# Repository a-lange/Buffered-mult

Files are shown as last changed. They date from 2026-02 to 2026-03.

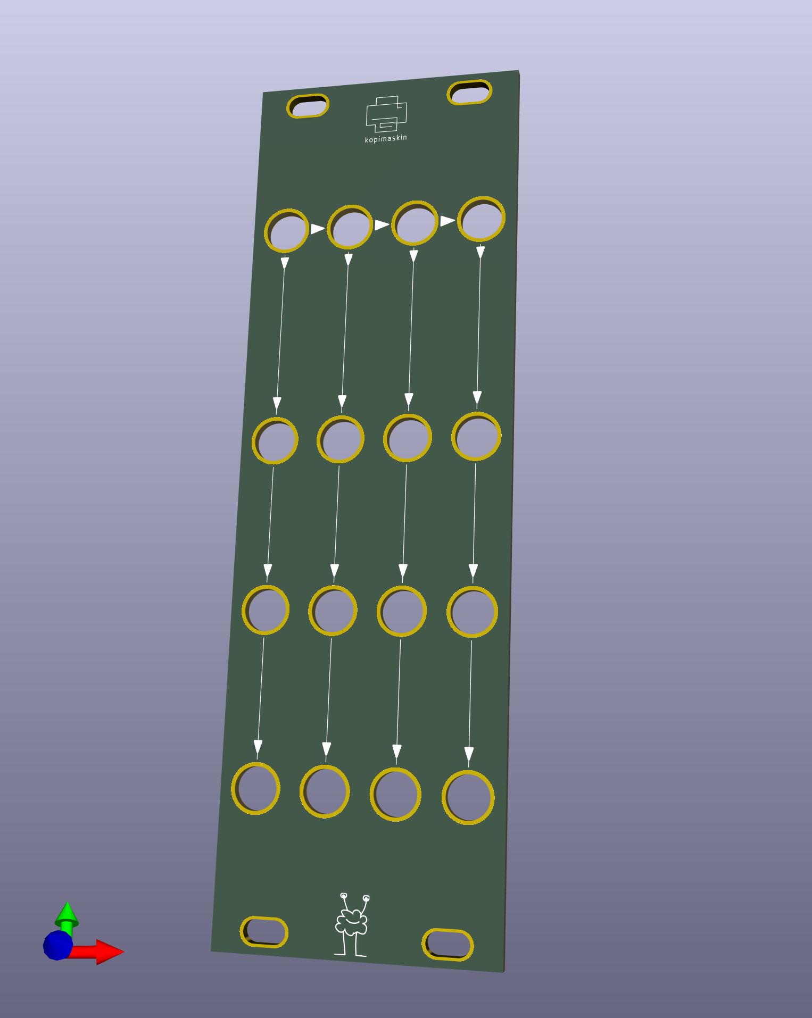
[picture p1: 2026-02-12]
PANEL.png

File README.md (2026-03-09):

This is a buffered mult, made in Kicad for 8HP format. 

It is tested, and works.

For now there is a few minor issues:
- power connector is too close to the edge, so it overhangs a tiny bit. So use an unkeyed pin-header and note that -12v(red stripe) is towards the edge of the board.
- GND is missing on the top jacks, easily patched manually.

The front panel is reversible, the back has a simpler layout with no logo, text or copier.

Use it however you like.

The text says 'copier' in Norwegian, and the creature on the bottom is the friendly "ullmann"(wool-man).
PANEL

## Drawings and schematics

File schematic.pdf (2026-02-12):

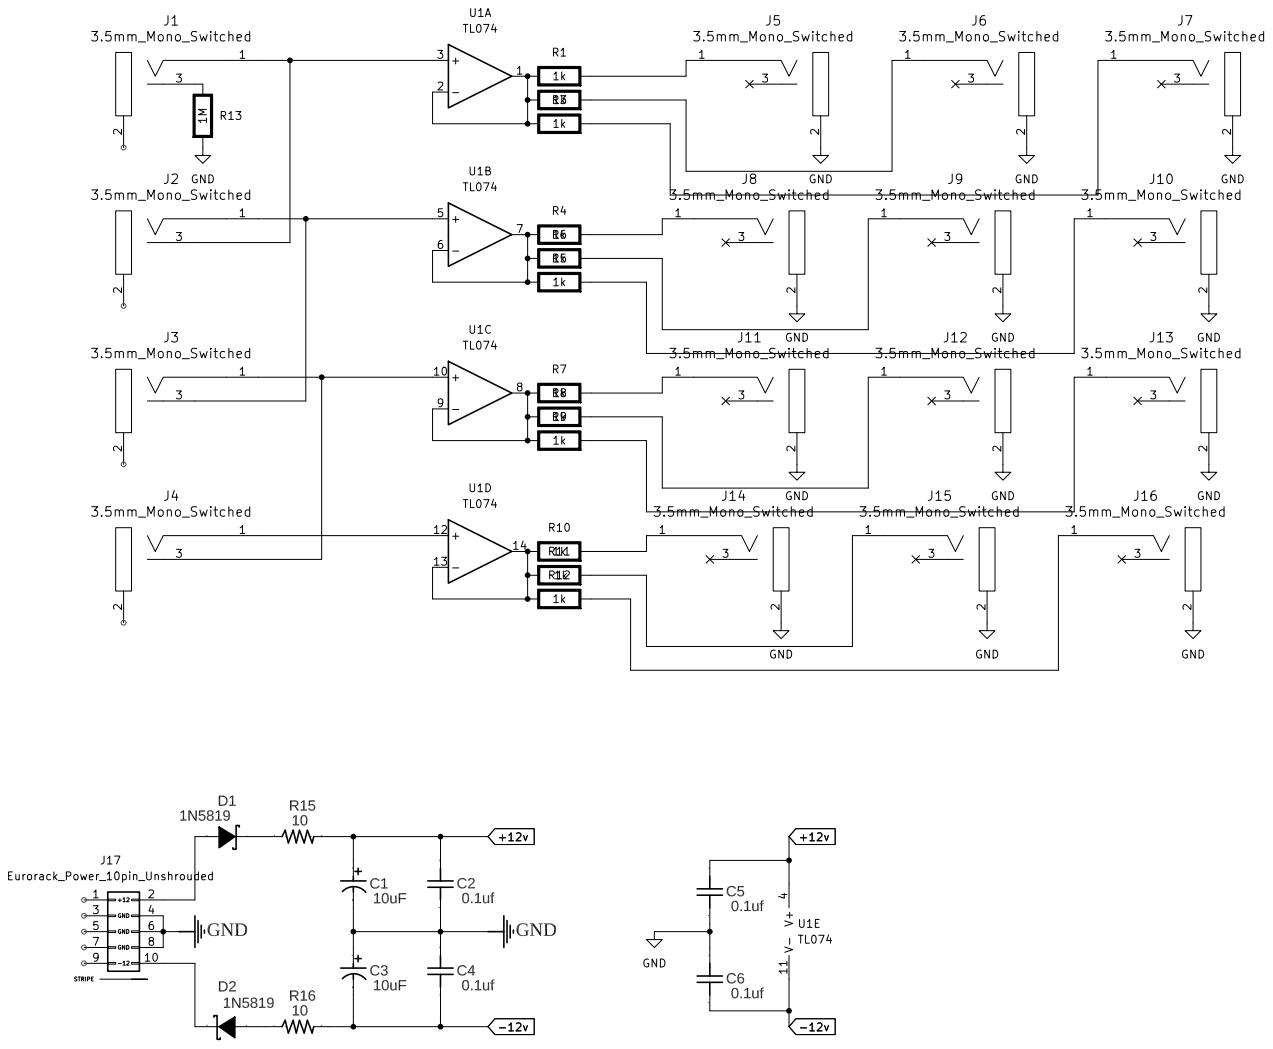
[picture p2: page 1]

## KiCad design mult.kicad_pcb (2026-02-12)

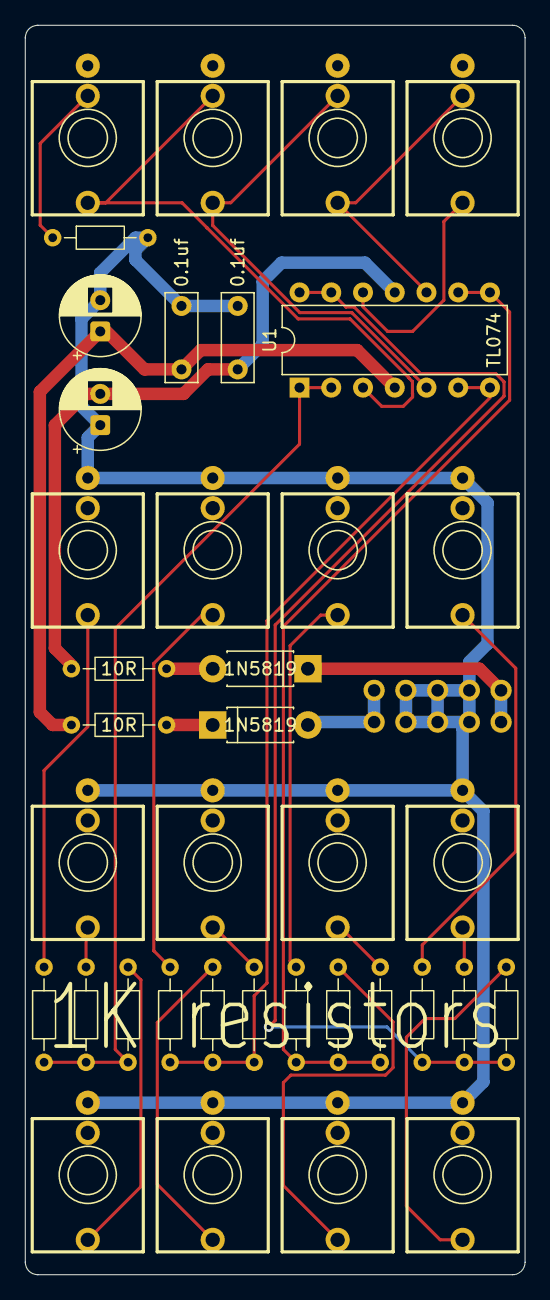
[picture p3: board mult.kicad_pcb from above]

Board: 2 copper layers, 40.0 x 100.0 mm, 39 parts (1 on the bottom side), 28 nets.

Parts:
C1, C3: 10uF; CP_Radial_D6.3mm_P2.50mm
C2, C4: 0.1uf; C_Disc_P5.08mm
D1, D2: 1N5819; D_DO-41_P7.62mm_Horizontal
J1, J2, J3, J4, J5, J6, J7, J8, J9, J10, J11, J12, J13, J14, J15, J16: EighthInch_PJ398SM
J17: Eurorack_Power_10pin_Unshrouded; Pins_2x05_2.54mm_TH
R1, R2, R3, R4, R5, R6, R7, R8, R9, R10, R11, R12: 1k; R_Axial_DIN0204_L3.6mm_D1.6mm_P7.62mm_Horizontal
R13: 1M; R_Axial_DIN0204_L3.6mm_D1.6mm_P7.62mm_Horizontal
R15, R16: 10R; R_Axial_DIN0204_L3.6mm_D1.6mm_P7.62mm_Horizontal
U1: TL074; DIP-14_W7.62mm

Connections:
+12v: C1.1, C2.2, R15.2, U1.4 (V+)
-12v: C3.2, C4.1, R16.2, U1.11 (V-)
GND: C1.2, C2.1, C3.1, C4.2, J5.2 (SHEILD), J6.2 (SHEILD), J7.2 (SHEILD), J8.2 (SHEILD), J9.2 (SHEILD), J10.2 (SHEILD), J11.2 (SHEILD), J12.2 (SHEILD), J13.2 (SHEILD), J14.2 (SHEILD), J15.2 (SHEILD), J16.2 (SHEILD), J17.3 (GND), J17.4 (GND), J17.5 (GND), J17.6 (GND), J17.7 (GND), J17.8 (GND), R13.2 (-)
unnamed: D1.2 (A), J17.1 (+12V), J17.2 (+12V)
unnamed: D1.1 (K), R15.1
unnamed: D2.2 (A), R16.1
unnamed: D2.1 (K), J17.9 (-12V), J17.10 (-12V)
unnamed: J1.1 (SIG), J2.3 (SW), U1.3 (+)
unnamed: J1.3 (SW), R13.1 (+)
unnamed: J2.1 (SIG), J3.3 (SW), U1.5 (+)
unnamed: J3.1 (SIG), J4.3 (SW), U1.10 (+)
unnamed: J4.1 (SIG), U1.12 (+)
unnamed: J5.1 (SIG), R1.2 (-)
unnamed: J6.1 (SIG), R2.2 (-)
unnamed: J7.1 (SIG), R3.2 (-)
unnamed: J8.1 (SIG), R4.2 (-)
unnamed: J9.1 (SIG), R6.2 (-)
unnamed: J10.1 (SIG), R5.2 (-)
unnamed: J11.1 (SIG), R7.2 (-)
unnamed: J12.1 (SIG), R8.2 (-)
unnamed: J13.1 (SIG), R9.2 (-)
unnamed: J14.1 (SIG), R10.2 (-)
unnamed: J15.1 (SIG), R11.2 (-)
unnamed: J16.1 (SIG), R12.2 (-)
unnamed: R1.1 (+), R2.1 (+), R3.1 (+), U1.1, U1.2 (-)
unnamed: R4.1 (+), R5.1 (+), R6.1 (+), U1.6 (-), U1.7
unnamed: R7.1 (+), R8.1 (+), R9.1 (+), U1.8, U1.9 (-)
unnamed: R10.1 (+), R11.1 (+), R12.1 (+), U1.13 (-), U1.14
